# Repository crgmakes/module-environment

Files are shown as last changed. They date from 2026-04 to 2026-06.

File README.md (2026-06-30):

# Aquarius Environment Module

Environment monitoring module. Temperature, light, VOC, NOX, etc.

# Software 

You will need [KiCad](https://kicad.org) to view and edit this design. Click [here](https://www.kicad.org/download/) to download.

You will also need all the associated libraries and models to drive the design if you want to make changes or view the 3D rendering:

https://github.com/crgmakes/kicad-library.git

Kicad MUST be configured properly to use all the files in this repo. Once you have Kicad installed, under Preferences->Configure Paths..., make the following entries:

1 - KICAD_USER_DIR -> set to the root location of where you placed the above repository.
2 - KICAD_USER_LIBRARY = ${KICAD_USER_DIR}/Library
3 - KICAD_USER_MODEL_DIR = ${KICAD_USER_LIBRARY}/models
4 - KICAD_USER_TEMPLATE_DIR	= ${KICAD_USER_LIBRARY}/templates	

Kicad will operate mostly normally if these are not set properly. You will notice an issue when you view the PCB in 3D mode.

***NOTE***: after makeing a release build in git, if your rendered 3D images are missing components, ensure the path to EVERY component model is set to ${KICAD_USER_MODEL_DIR}/<model name>.

Kicad sometimes replaces the variable with an expansion and that FAILS during the build process because the expanded variable is local and does not match the build environment.

---

THE DESIGN IS PROVIDED "AS IS" AND THE AUTHOR DISCLAIMS ALL WARRANTIES WITH REGARD TO THIS DESIGN INCLUDING ALL IMPLIED WARRANTIES OF MERCHANTABILITY AND FITNESS. IN NO EVENT SHALL THE AUTHOR BE LIABLE FOR ANY SPECIAL, DIRECT, INDIRECT, OR CONSEQUENTIAL DAMAGES OR ANY DAMAGES WHATSOEVER RESULTING FROM LOSS OF USE, DATA OR PROFITS, WHETHER IN AN ACTION OF CONTRACT, NEGLIGENCE OR OTHER TORTIOUS ACTION, ARISING OUT OF OR IN CONNECTION WITH THE USE OR PERFORMANCE OF THIS DESIGN.

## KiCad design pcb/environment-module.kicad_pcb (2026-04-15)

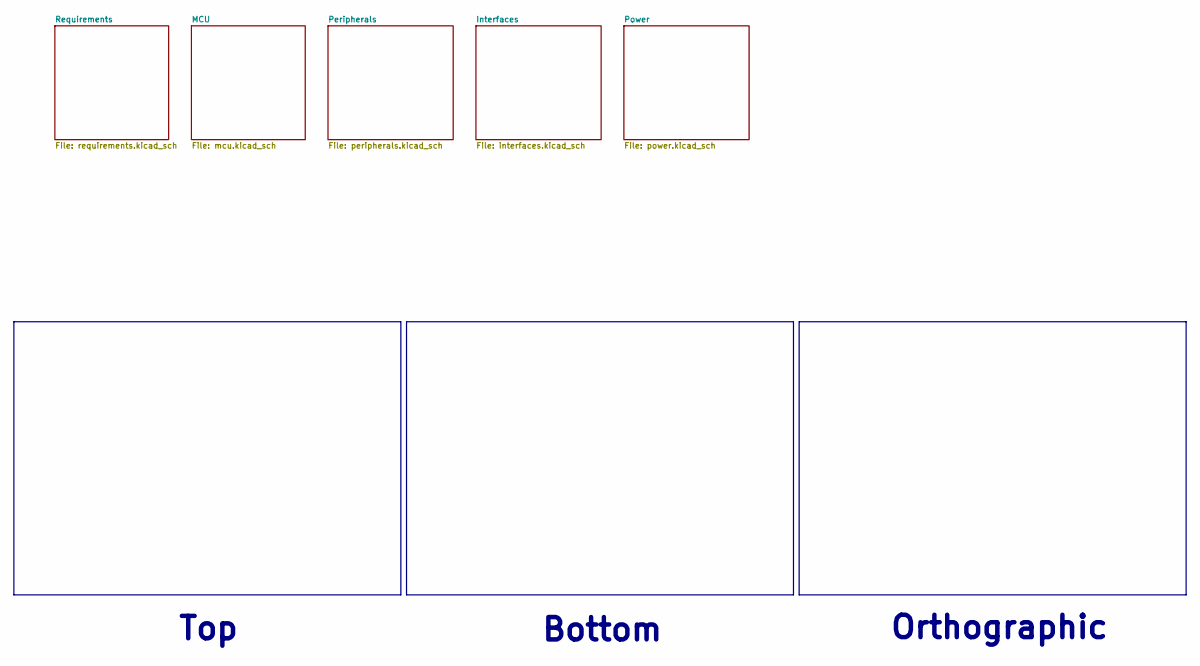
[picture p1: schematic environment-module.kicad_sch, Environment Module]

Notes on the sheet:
Bottom
Top
Orthographic

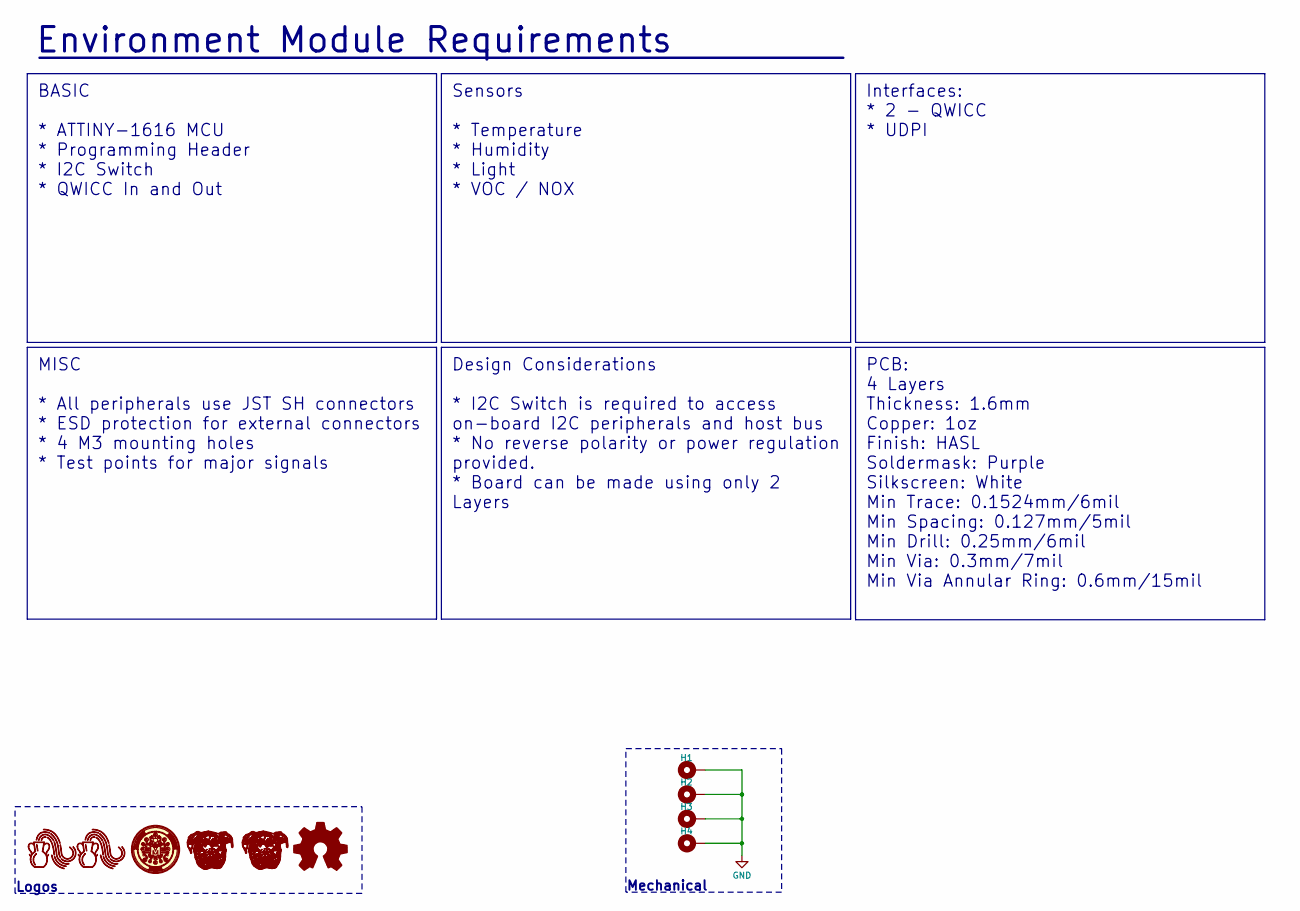
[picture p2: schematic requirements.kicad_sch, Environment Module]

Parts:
H1, H2, H3, H4: MountingHole_3.2mm_M3_Pad_Via
LOGO1, LOGO2: Aquarius Logo 5mm
LOGO3: CRGM Logo 7mm
LOGO4, LOGO5: Roxy 6.5mm
LOGO6: OSHW-Logo_5.7x6mm_SilkScreen

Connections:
GND: H1.1, H2.1, H3.1, H4.1; also elsewhere on the board

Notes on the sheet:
Logos
Environment Module Requirements
Mechanical
Interfaces: * 2 - QWICC * UDPI
PCB: 4 Layers Thickness: 1.6mm Copper: 1oz Finish: HASL Soldermask: Purple Silkscreen: White Min Trace: 0.1524mm/6mil Min Spacing: 0.127mm/5mil Min Drill: 0.25mm/6mil Min Via: 0.3mm/7mil Min Via Annular Ring: 0.6mm/15mil
BASIC * ATTINY-1616 MCU * Programming Header * I2C Switch * QWICC In and Out
MISC * All peripherals use JST SH connectors * ESD protection for external connectors * 4 M3 mounting holes * Test points for major signals
Sensors * Temperature * Humidity * Light * VOC / NOX
Design Considerations * I2C Switch is required to access on-board I2C peripherals and host bus * No reverse polarity or power regulation provided. * Board can be made using only 2 Layers

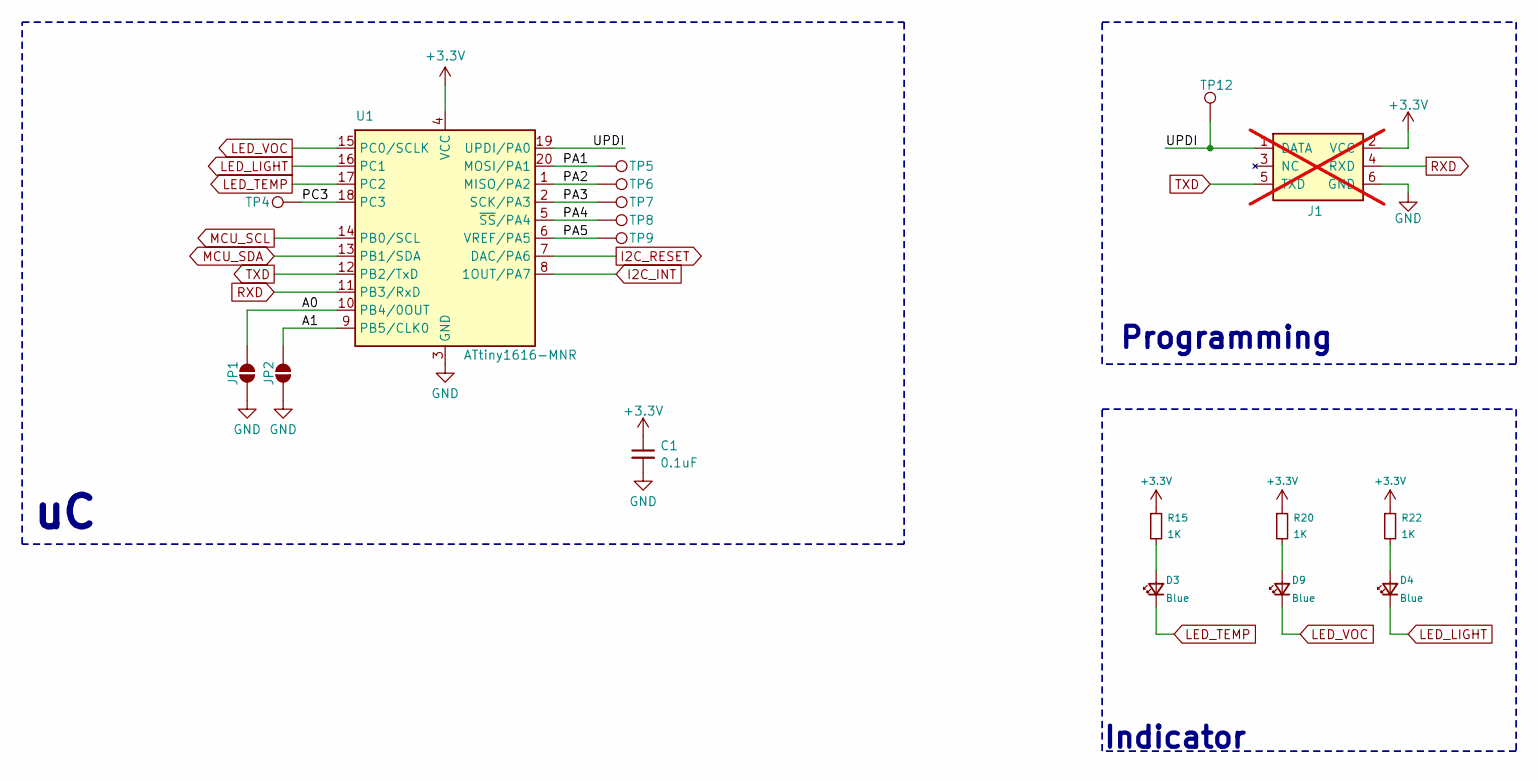
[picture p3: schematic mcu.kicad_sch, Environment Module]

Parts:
C1: 0.1uF; C_0603_1608Metric; Tolerance 10%; MPN CL10B104KO8NNNC; LCSC C66501
D3, D4, D9: Blue; LED_0603_1608Metric; MPN XL-1608UBC-04; Mouser 859-LTST-C190TBKT
J1: AVR-UPDI-6; PinHeader_2x03_P2.54mm_Vertical_SMD; not fitted
JP1, JP2: SolderJumper-2_P1.3mm_Open_RoundedPad1.0x1.5mm
R15, R20, R22: 1K; R_0603_1608Metric; Tolerance 5%; MPN FRC0603J102 TS; Mouser 71-CRCW06031K00JNEAC
TP4, TP5, TP6, TP7, TP8, TP9, TP12: TestPoint_Pad_D1.0mm
U1: ATtiny1616-MNR; VQFN-20-1EP_3x3mm_P0.4mm_EP1.7x1.7mm_ThermalVias; MPN ATTINY1616-MNR; Mouser 556-ATTINY1616MNR

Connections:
+3.3V: C1.1, J1.2 (VCC), R15.1, R20.1, R22.1, U1.4 (VCC); also elsewhere on the board
/MCU/A0: JP1.2 (B), U1.10 (PB4/0OUT)
/MCU/A1: JP2.2 (B), U1.9 (PB5/CLK0)
/MCU/PA1: TP5.1, U1.20 (MOSI/PA1)
/MCU/PA2: TP6.1, U1.1 (MISO/PA2)
/MCU/PA3: TP7.1, U1.2 (SCK/PA3)
/MCU/PA4: TP8.1, U1.5 (~SS/PA4)
/MCU/PA5: TP9.1, U1.6 (VREF/PA5)
/MCU/PC3: TP4.1, U1.18 (PC3)
/MCU/UPDI: J1.1 (DATA), TP12.1, U1.19 (UPDI/PA0)
GND: C1.2, J1.6 (GND), JP1.1 (A), JP2.1 (A), U1.3 (GND), U1.21 (GND); also elsewhere on the board
I2C_INT: U1.8 (1OUT/PA7); also elsewhere on the board
I2C_RESET: U1.7 (DAC/PA6); also elsewhere on the board
LED_LIGHT: D4.1 (K), U1.16 (PC1)
LED_TEMP: D3.1 (K), U1.17 (PC2)
LED_VOC: D9.1 (K), U1.15 (PC0/SCLK)
MCU_SCL: U1.14 (PB0/SCL); also elsewhere on the board
MCU_SDA: U1.13 (PB1/SDA); also elsewhere on the board
unnamed: D3.2 (A), R15.2
unnamed: D4.2 (A), R22.2
unnamed: D9.2 (A), R20.2
RXD: J1.4 (RXD), U1.11 (PB3/RxD)
TXD: J1.5 (TXD), U1.12 (PB2/TxD)

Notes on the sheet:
Programming
Indicator

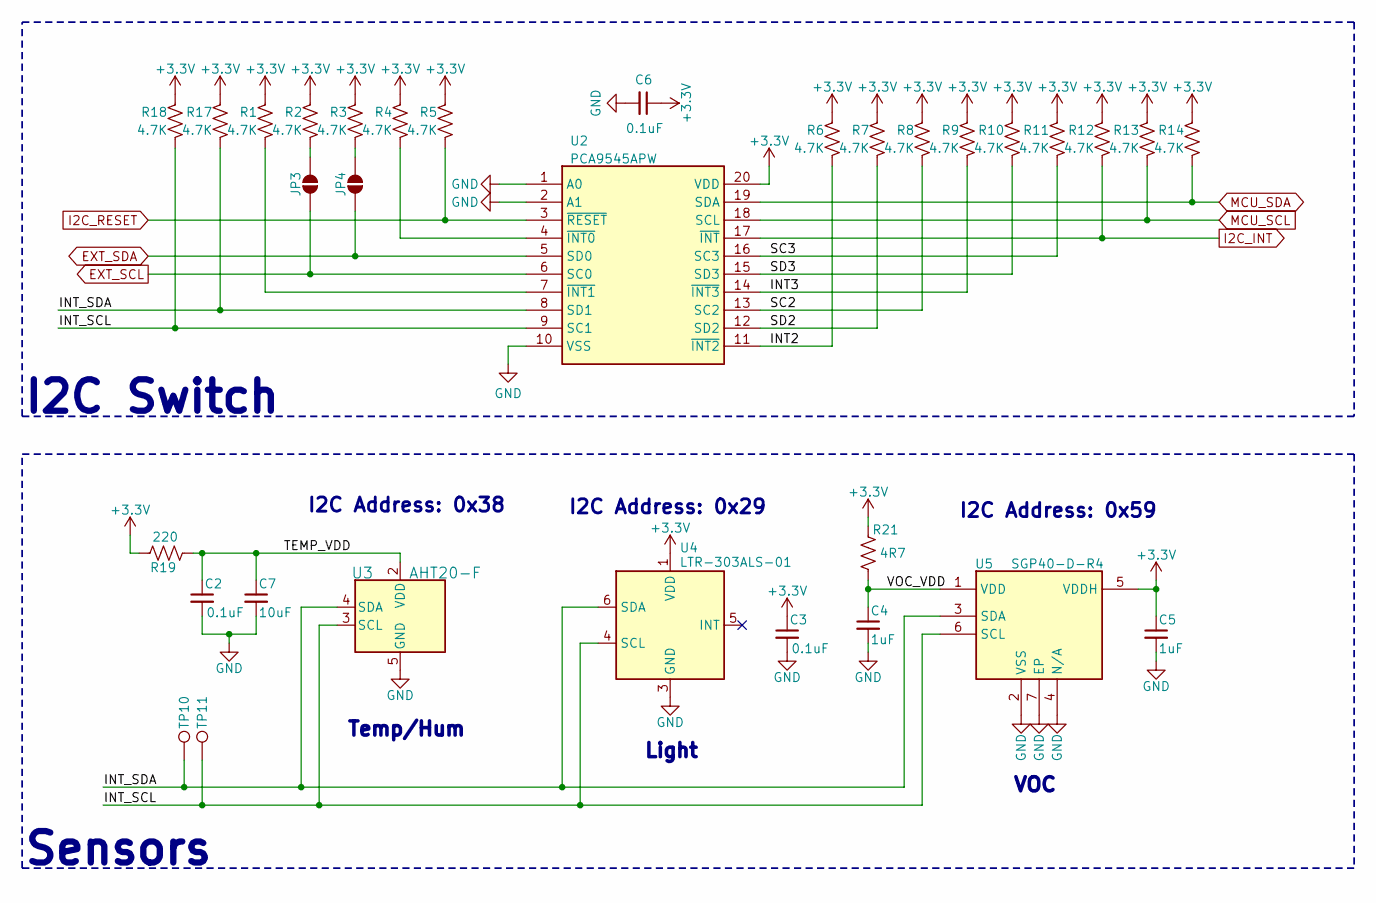
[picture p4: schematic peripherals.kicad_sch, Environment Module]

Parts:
C2, C3: 0.1uF; C_0603_1608Metric; Tolerance 10%; MPN CL10B104KO8NNNC; Digikey 1276-1005-2-ND
C4, C5: 1uF; C_0603_1608Metric; Tolerance 10%; MPN CGA0603X5R105K160JT; Mouser 187-CL10B105KO8NNNC
C6: 0.1uF; C_0603_1608Metric; Tolerance 10%; MPN CL10B104KO8NNNC; LCSC C66501
C7: 10uF; C_0603_1608Metric; Tolerance 10%; MPN CGA0603X5R106K100JT; Mouser 187-CL10A106KP8NNNC
JP3, JP4: SolderJumper-2_P1.3mm_Open_RoundedPad1.0x1.5mm
R1, R2, R3, R4, R5, R6, R7, R9, R10, R12, R13, R17, R18: 4.7K; R_0603_1608Metric; Tolerance 5%; MPN FRC0603J472 TS; Mouser 71-CRCW06034K70JNEAC
R8, R11, R14: 4.7K; R_0603_1608Metric; Tolerance 5%; MPN FRC0603J472 TS; LCSC C2907166
R19: 220; R_0603_1608Metric; Tolerance 5%; MPN FRC0603J221 TS; Mouser 652-CR0603JW-221ELF
R21: 4R7; R_0603_1608Metric; Tolerance 5%; MPN FRC0603J4R7 TS; Mouser 652-CR0603JW-4R7ELF
TP10, TP11: TestPoint_Pad_D1.0mm
U2: PCA9545APW; SOP65P640X110-20N; MPN PCA9545APW,118; Digikey 568-1865-2-ND
U3: AHT20-F; AHT20; MPN AHT20-F; LCSC C3012622
U4: LTR-303ALS-01; MPN LTR-303ALS-01; Digikey 160-2161-2-ND
U5: SGP40-D-R4; SON80P244X244X95-7N; MPN SGP40-D-R4; Digikey 1649-SGP40-D-R4TR-ND

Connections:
+3.3V: C3.1, C5.1, C6.1, R1.2, R2.2, R3.2, R4.2, R5.2, R6.2, R7.2, R8.2, R9.2, R10.2, R11.2, R12.2, R13.2, R14.2, R17.2, R18.2, R19.1, R21.1, U2.20 (VDD), U4.1 (VDD), U5.5 (VDDH); also elsewhere on the board
/Peripherals/INT2: R6.1, U2.11 (~INT2)
/Peripherals/INT3: R9.1, U2.14 (~INT3)
/Peripherals/INT_SCL: R18.1, TP11.1, U2.9 (SC1), U3.3 (SCL), U4.4 (SCL), U5.6 (SCL)
/Peripherals/INT_SDA: R17.1, TP10.1, U2.8 (SD1), U3.4 (SDA), U4.6 (SDA), U5.3 (SDA)
/Peripherals/SC2: R8.1, U2.13 (SC2)
/Peripherals/SC3: R11.1, U2.16 (SC3)
/Peripherals/SD2: R7.1, U2.12 (SD2)
/Peripherals/SD3: R10.1, U2.15 (SD3)
/Peripherals/TEMP_VDD: C2.1, C7.1, R19.2, U3.2 (VDD)
/Peripherals/VOC_VDD: C4.1, R21.2, U5.1 (VDD)
EXT_SCL: JP3.1 (A), U2.6 (SC0); also elsewhere on the board
EXT_SDA: JP4.1 (A), U2.5 (SD0); also elsewhere on the board
GND: C2.2, C3.2, C4.2, C5.2, C6.2, C7.2, U2.1 (A0), U2.2 (A1), U2.10 (VSS), U3.5 (GND), U4.3 (GND), U5.2 (VSS), U5.4 (N/A), U5.7 (EP); also elsewhere on the board
I2C_INT: R12.1, U2.17 (~INT); also elsewhere on the board
I2C_RESET: R5.1, U2.3 (~RESET); also elsewhere on the board
MCU_SCL: R13.1, U2.18 (SCL); also elsewhere on the board
MCU_SDA: R14.1, U2.19 (SDA); also elsewhere on the board
unnamed: JP3.2 (B), R2.1
unnamed: JP4.2 (B), R3.1
unnamed: R4.1, U2.4 (~INT0)
unnamed: R1.1, U2.7 (~INT1)

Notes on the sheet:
I2C Address: 0x29
I2C Address: 0x59
Light
Sensors
VOC
Temp/Hum
I2C Switch
I2C Address: 0x38

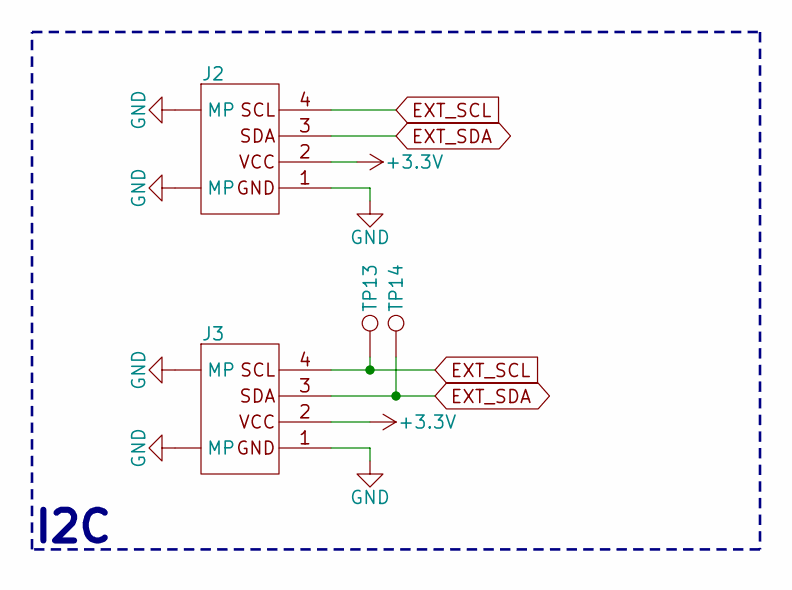
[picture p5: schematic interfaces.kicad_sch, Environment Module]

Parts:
J2, J3: JST_SH_BM04B-SRSS-TB_1x04-1MP_P1.00mm_Vertical; MPN BM04B-SRSS-TBT(LF)(SN); Mouser 306-BM04BSRSSTBTLFSN
TP13, TP14: TestPoint_Pad_D1.0mm

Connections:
+3.3V: J2.2, J3.2; also elsewhere on the board
EXT_SCL: J2.4, J3.4, TP13.1; also elsewhere on the board
EXT_SDA: J2.3, J3.3, TP14.1; also elsewhere on the board
GND: J2.0 (MP), J2.1, J2.5 (MP), J3.0 (MP), J3.1, J3.5 (MP); also elsewhere on the board

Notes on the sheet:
I2C

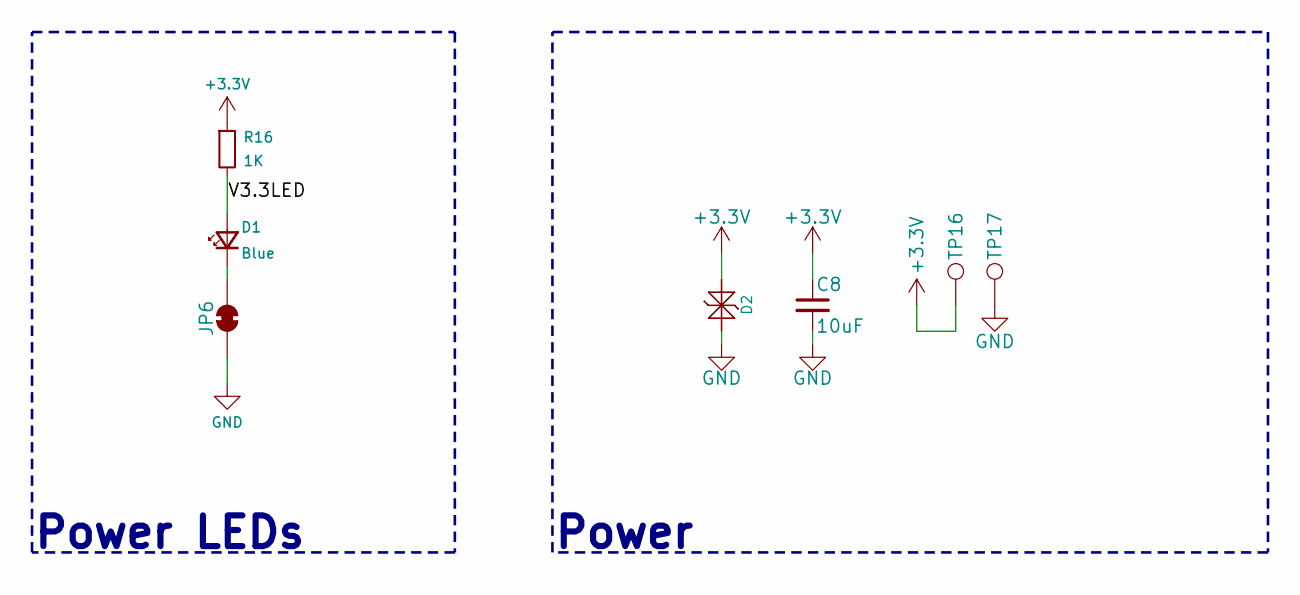
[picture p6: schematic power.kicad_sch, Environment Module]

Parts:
C8: 10uF; C_0603_1608Metric; Tolerance 10%; MPN CGA0603X5R106K100JT; Mouser 187-CL10A106KP8NNNC
D1: Blue; LED_0603_1608Metric; MPN XL-1608UBC-04; Mouser 859-LTST-C190TBKT
D2: PESD3V3S1BL; DFN1006-2; MPN LESD8D3.3CAT5G; LCSC C5563754
JP6: SolderJumper-2_P1.3mm_Bridged_RoundedPad1.0x1.5mm
R16: 1K; R_0603_1608Metric; Tolerance 5%; MPN FRC0603J102 TS; Mouser 71-CRCW06031K00JNEAC
TP16, TP17: TestPoint_Pad_D1.0mm

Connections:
+3.3V: C8.1, D2.2 (K2), R16.1, TP16.1; also elsewhere on the board
/Power/V3.3LED: D1.2 (A), R16.2
GND: C8.2, D2.1 (K1), JP6.1 (A), TP17.1; also elsewhere on the board
unnamed: D1.1 (K), JP6.2 (B)

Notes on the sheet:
Power LEDs
Power

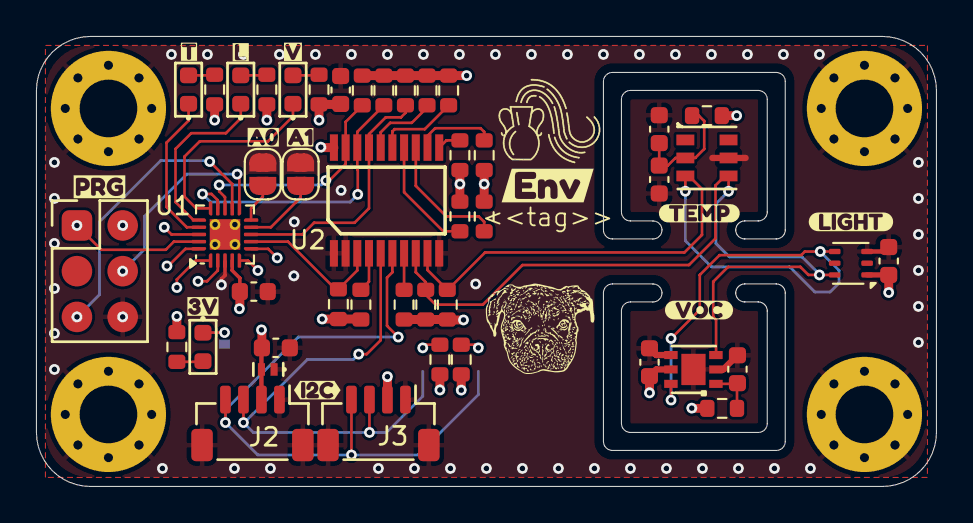
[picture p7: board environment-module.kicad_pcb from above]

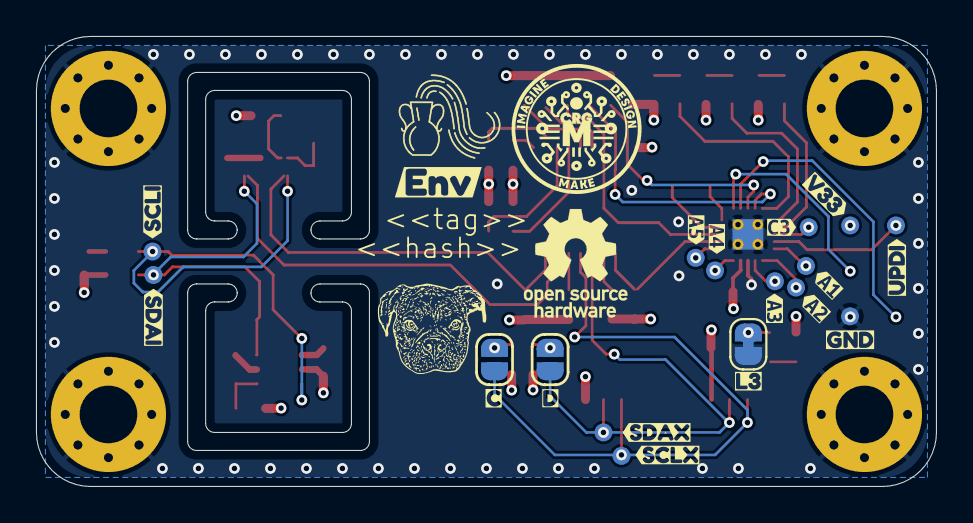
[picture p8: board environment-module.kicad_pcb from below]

Board: 4 copper layers, 50.0 x 25.0 mm, 100 parts (37 on the bottom side), 41 nets.

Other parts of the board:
kibuzzard-68F7F6D5: G***; kibuzzard-68F7F6D5
kibuzzard-68F7F6E1: G***; kibuzzard-68F7F6E1
kibuzzard-68FAFDB2: G***; kibuzzard-68FAFDB2
kibuzzard-68FAFDB8: G***; kibuzzard-68FAFDB8
kibuzzard-68FC4C70: G***; kibuzzard-68FC4C70
kibuzzard-69C852DC: G***; kibuzzard-69C852DC
kibuzzard-69C852F0: G***; kibuzzard-69C852F0
kibuzzard-69DC4F1F: G***; kibuzzard-69DC4F1F
kibuzzard-69DC4F14: G***; kibuzzard-69DC4F14
kibuzzard-69DC4F46: G***; kibuzzard-69DC4F46
kibuzzard-69DC53A1: G***; kibuzzard-69DC53A1
kibuzzard-69DC5370: G***; kibuzzard-69DC5370
kibuzzard-69DEF070: G***; kibuzzard-69DEF070
kibuzzard-690A7D98: G***; kibuzzard-690A7D98
kibuzzard-690D67E0: G***; kibuzzard-690D67E0
kibuzzard-690D683A: G***; kibuzzard-690D683A
kibuzzard-690D6815: G***; kibuzzard-690D6815
kibuzzard-690D6835: G***; kibuzzard-690D6835
kibuzzard-691D233B: G***; kibuzzard-691D233B
kibuzzard-6902B41D: G***; kibuzzard-6902B41D
kibuzzard-6902BBCC: G***; kibuzzard-6902BBCC
kibuzzard-6908DD87: G***; kibuzzard-6908DD87
kibuzzard-6952D1DF: G***; kibuzzard-6952D1DF
kibuzzard-6952D1FF: G***; kibuzzard-6952D1FF
kibuzzard-6952D20C: G***; kibuzzard-6952D20C
kibuzzard-69029C60: G***; kibuzzard-69029C60
kibuzzard-69571EBA: G***; kibuzzard-69571EBA
kibuzzard-69571EDB: G***; kibuzzard-69571EDB
kibuzzard-69571F0B: G***; kibuzzard-69571F0B

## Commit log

2025-10-30 Initial check in
    [interfaces.kicad_sch, mcu.kicad_sch, module-environment.kicad_sch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]
2025-11-02 Fixed LTR address from 0x80 to 0x40
    [peripherals.kicad_sch]
2025-11-03 Updates for consistency
    Changed mounting holes to grounded
    Updated power connectors
    Added power ESD protection
    [interfaces.kicad_sch, power.kicad_sch, requirements.kicad_sch]
2025-11-03 Swapped temp sensor for more popular model
    Changed HDC1080 for AHT20
    Updated reference layer
    Updated renders
    Updated requirements
    Fixed models
    [peripherals.kicad_sch, power.kicad_sch, requirements.kicad_sch]
2025-11-04 Switched back to global lables
    Updated all gnd and test point symbols
    [interfaces.kicad_sch, mcu.kicad_sch, peripherals.kicad_sch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]
2025-11-04 Updated footprints for DFM
2025-11-04 Updated for DFM
    Cleaned up board
    Updated footprints
    Adjusted silkscreen
    Fixed panel options name
    Changed project name
    [interfaces.kicad_sch, mcu.kicad_sch, peripherals.kicad_sch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]
2025-11-05 Updated silkscreen
2025-11-19 Fixed sillkscreen and renders
    [requirements.kicad_sch]
2025-12-27 Moved sensors to edge of board
    Adjusted routing and silkscreen
    [peripherals.kicad_sch]
2025-12-28 Changed I2C to open instead of bridged
    Moved I2C jumper to back
    Changed to open instead of bridged
    Changed Roxy to 5mm on front
    Moved silkscreen around.
    Removed logos from BOM
    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
    [environment-module.kicad_pcb, environment-module.kicad_sch, peripherals.kicad_sch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]
2025-12-29 Added labels for sensors
    Fixed part numbers for connectors
    Remove unnecessary property values
    [environment-module.kicad_pcb, environment-module.kicad_sch, interfaces.kicad_sch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]
2025-12-29 Updated fab layer references
    [environment-module.kicad_pcb]
2026-01-02 Redesign with cutouts for sensors
    Removed power connectors since 5V is not needed
    Added cutout for VOC sensor
    Rerouted sensor section
    Rescaled logos and fixed silkscreen
    Changed to blue LED for power indicator
    Updated requirements and renders
    Changed all 0.1uF caps to small symbol
    [environment-module.kicad_pcb, environment-module.kicad_sch, mcu.kicad_sch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]
2026-01-03 Removed FNWW logo
    Adjusted silkscreen on back
    [environment-module.kicad_pcb, requirements.kicad_sch]
2026-03-01 replaced .wrl with .step
    [environment-module.kicad_pcb]
2026-04-13 Updated UPDI Connector
    Integrated serial and UPDI
    Changed to vertical connectors
    Rounded cutouts
    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
    [environment-module.kicad_pcb, environment-module.kicad_sch, interfaces.kicad_sch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]
2026-04-13 Closed #3
    Added status LEDs -- updated
    Updated silkscreen
    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
    [environment-module.kicad_pcb, environment-module.kicad_sch, mcu.kicad_sch]
2026-04-15 Changed to inside cutouts
    Increased size of Roxy on front ❤️
    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
    [environment-module-panel.kicad_pcb, environment-module.kicad_pcb, environment-module.kicad_sch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]
2026-04-15 Rounded cutouts
    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
    [environment-module.kicad_pcb, environment-module.kicad_sch]
2026-04-15 Changed post radius to 0.1mm
    No internal cutouts with a 'normal' sized radius.
    [environment-module-panel.kicad_pcb]
2026-04-15 Removed mill radius and added outer
    Fixes panel frame radius problems.
2026-04-15 Adjusted spacing and alignment of parts
    Moved temp and voc to be on grid
    Ran ERC -- fixed errors
    Ran DRC -- fixed errors
    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
    [environment-module.kicad_pcb, environment-module.kicad_sch, mcu.kicad_sch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]
